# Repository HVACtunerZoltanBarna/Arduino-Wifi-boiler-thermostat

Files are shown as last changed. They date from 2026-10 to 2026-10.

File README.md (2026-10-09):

# Arduino-Wifi-boiler-thermostat
Tested, Super stable Arduino thermostat board, with Wifi board.
I wanted to build something like an industrilal system with arduinos. 
This project has to boards. One is R3 UNO, other is R4 UNO WIFI.
The R3 controls the boiler relay, and checks flow/ return/ room temperatures. 
Watchdog running on the R3 so if the code is frozen, then it restartes itself.
R4 wifi runs heartbeat signal. If R4 is frozen then R3 restarts it.
R4 also emits "CloudOK" signal. (for example cloud is unreachable, or wifi is off, or just R4 is dropped off from Wifi). If this signal is false for certain time, then R3 restarts it.
The setpoint is arrives from the Cloud, and uploads to the R3. If nothing arrives then R3 runs from the latest setpoint. If no wifi and the power just came back, the default settemp is 14°C.
If R3 founds error  (for example bad sensor, or no heating) if forwards the error towards the R4 which uploads it to the cloud.

You can download the code and the circuit diagram too.
The circuit diagram contains a tested blackout circuit too. (if the VIN voltage is too low then it pulls down the Reset pin of the R3).
PLS  give me some feedback see how it works in the huge world. :)
Sincerely: Zoltán.

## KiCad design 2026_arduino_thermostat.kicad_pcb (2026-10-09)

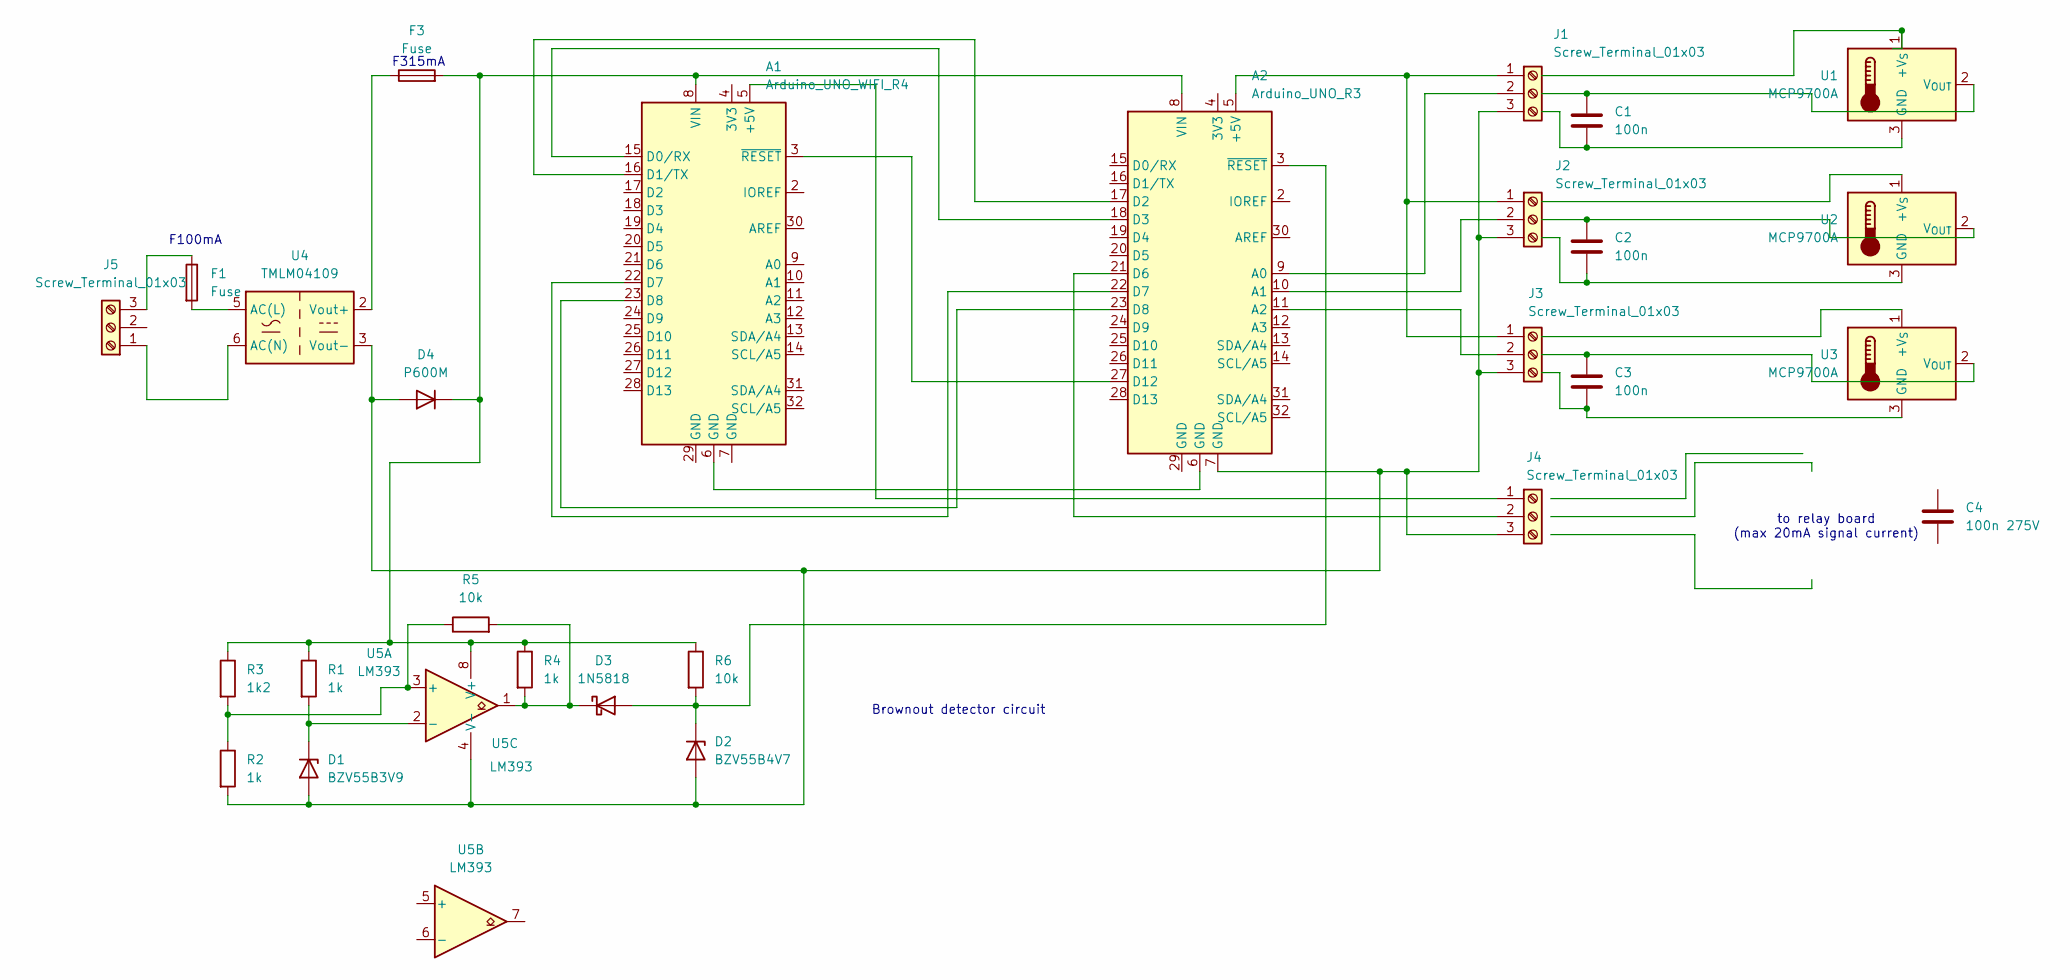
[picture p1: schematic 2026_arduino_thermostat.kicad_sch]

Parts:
A1: Arduino_UNO_WIFI_R4; Arduino_UNO_R3
A2: Arduino_UNO_R3
C1, C2, C3: 100n; C_Disc_D7.5mm_W4.4mm_P5.00mm
C4: 100n 275V
D1: BZV55B3V9; D_A-405_P7.62mm_Horizontal
D2: BZV55B4V7; D_A-405_P7.62mm_Horizontal
D3: 1N5818; D_DO-35_SOD27_P7.62mm_Horizontal
D4: P600M; D_5W_P12.70mm_Horizontal
F1: Fuse; Littelfuse_Package_H_XBN2MM
F3: Fuse; Fuseholder_Littelfuse_445_030_series_5x25mm
J1, J2, J3, J4, J5: Screw_Terminal_01x03; Tag-Connect_TC2030-IDC-FP_2x03_P1.27mm_Vertical
R1, R2, R4: 1k; R_Axial_DIN0204_L3.6mm_D1.6mm_P7.62mm_Horizontal
R3: 1k2; R_Axial_DIN0204_L3.6mm_D1.6mm_P7.62mm_Horizontal
R5, R6: 10k; R_Axial_DIN0204_L3.6mm_D1.6mm_P7.62mm_Horizontal
U1, U2, U3: MCP9700A; TO-92_Inline
U4: TMLM04109; Converter_ACDC_TRACO_TMLM-04_THT
U5: LM393; DIP-8_W7.62mm

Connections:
unnamed: A1.5 (+5V), J4.1
unnamed: A1.15 (D0/RX), A2.18 (D3)
unnamed: A1.16 (D1/TX), A2.17 (D2)
unnamed: A1.22 (D7), A2.22 (D7)
unnamed: A1.23 (D8), A2.23 (D8)
unnamed: A1.6 (GND), A2.6 (GND)
unnamed: A1.8 (VIN), A2.8 (VIN), D4.1 (K), F3.2, R1.1, R3.1, R4.1, R6.1, U5.8 (V+)
unnamed: A1.3 (~RESET), A2.27 (D12)
unnamed: A2.5 (+5V), J1.1, J2.1, J3.1
unnamed: A2.9 (A0), J1.2
unnamed: A2.10 (A1), J2.2
unnamed: A2.11 (A2), J3.2
unnamed: A2.21 (D6), J4.2
unnamed: A2.3 (~RESET), D2.1 (K), D3.2 (A), R6.2
unnamed: A2.7 (GND), D1.2 (A), D2.2 (A), D4.2 (A), J1.3, J2.3, J3.3, J4.3, R2.2, U4.3 (Vout-), U5.4 (V-)
unnamed: D1.1 (K), R1.2, U5.2 (-)
unnamed: D3.1 (K), R4.2, R5.2, U5.1
unnamed: J5.1, U4.6 (AC(N))
unnamed: F1.1, J5.3
unnamed: C1.2, U1.3 (GND)
unnamed: C1.1, U1.2 (V_{OUT})
unnamed: C2.2, U2.3 (GND)
unnamed: C2.1, U2.2 (V_{OUT})
unnamed: C3.2, U3.3 (GND)
unnamed: C3.1, U3.2 (V_{OUT})
unnamed: F1.2, U4.5 (AC(L))
unnamed: F3.1, U4.2 (Vout+)
unnamed: R2.1, R3.2, R5.1, U5.3 (+)

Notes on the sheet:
F315mA
to relay board (max 20mA signal current)
F100mA
Brownout detector circuit

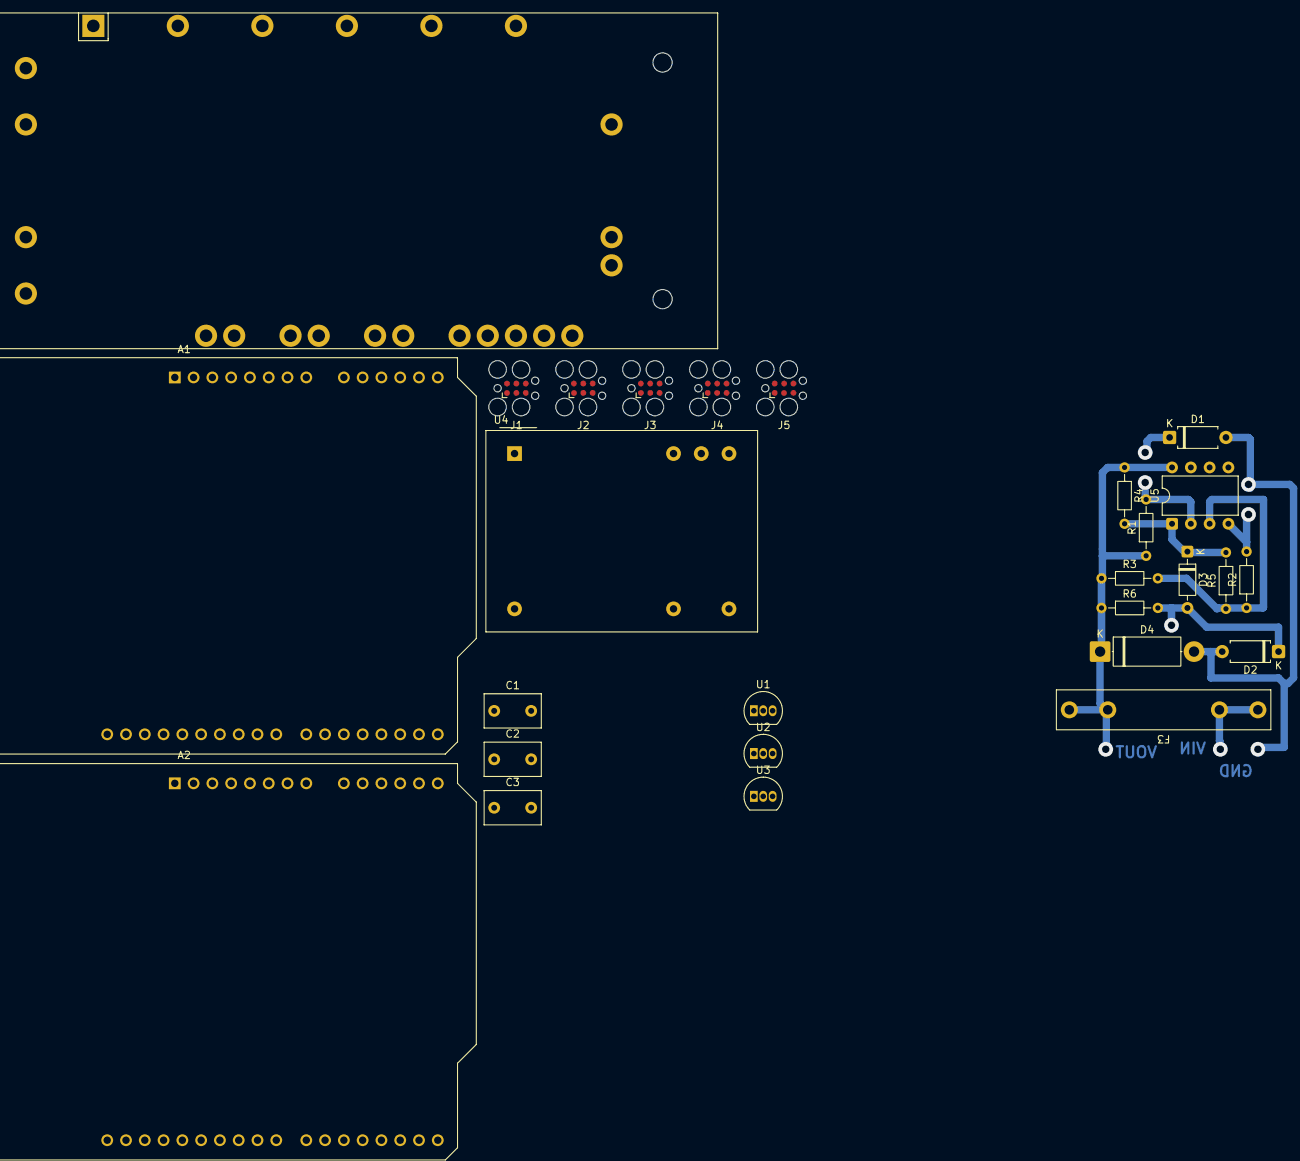
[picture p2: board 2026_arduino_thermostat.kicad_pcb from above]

Board: 2 copper layers, 27 parts (0 on the bottom side), 28 nets.
